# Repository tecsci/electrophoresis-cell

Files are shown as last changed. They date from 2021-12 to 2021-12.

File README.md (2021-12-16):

# Cuba de electroforesis de IORODEO

Links:

* Instructables versión mini: https://www.instructables.com/Gel-electrophoresis-system-mini/
* Sitio oficial documentacion: https://iorodeo.com/pages/documentation

## Fuente

Ver: https://github.com/tecsci/electrophoresis-power-supply

## Otros diseños

Parametric Gel Electrophoresis System: http://www.docubricks.com/viewer.jsp?id=3540694571097352192

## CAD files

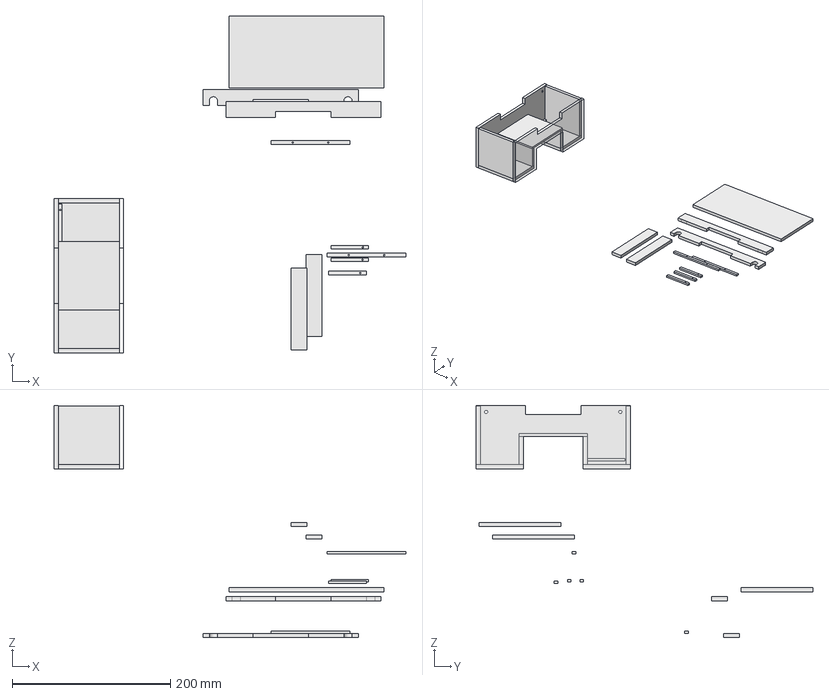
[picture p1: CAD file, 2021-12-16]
modelos/assembly.FCStd
444.4 x 425.5 x 293.3 mm
modelos_parametricos_0.125inch_clear_acrylic001_001
modelos_parametricos_0.125inch_clear_acrylic002_001
modelos_parametricos_0.125inch_clear_acrylic003_001
modelos_parametricos_0.125inch_clear_acrylic004_001
modelos_parametricos_0.125inch_clear_acrylic005_001
modelos_parametricos_0.125inch_clear_acrylic006_001
modelos_parametricos_0.25_inch_blue001_001
modelos_parametricos_0.25_inch_blue002_001
modelos_parametricos_0.25_inch_blue003_001
modelos_parametricos_0.25_inch_blue004_001
modelos_parametricos_0.25_inch_blue005_001
modelos_parametricos_0.25_inch_blue006_001
modelos_parametricos_0.25inch_clear_acrylic001_001
modelos_parametricos_0.25inch_clear_acrylic002_001
modelos_parametricos_0.25inch_clear_acrylic003_001
modelos_parametricos_0.25inch_clear_acrylic004_001
modelos_parametricos_0.25inch_clear_acrylic005_001
modelos_parametricos_0.25inch_clear_acrylic006_001
modelos_parametricos_0.25inch_clear_acrylic007_001
modelos_parametricos_0.125inch_solacryl_001

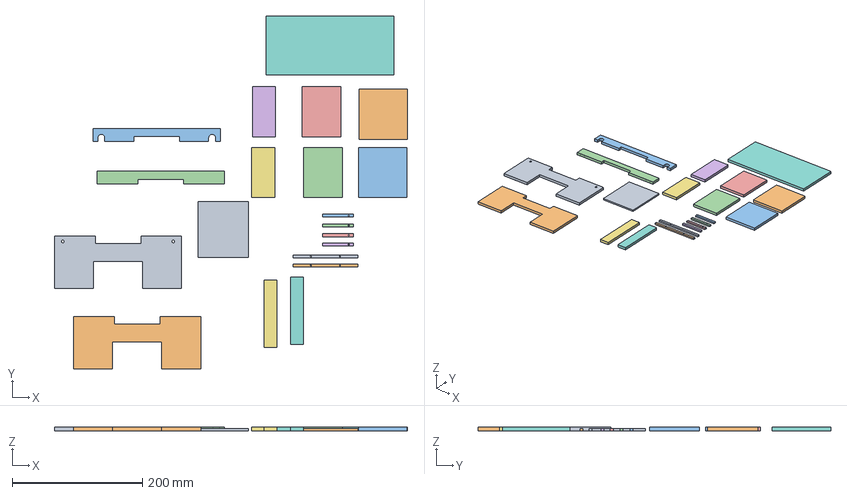
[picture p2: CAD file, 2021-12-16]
modelos/modelos_parametricos.FCStd
541.1 x 541.1 x 5.50 mm
0.125inch_solacryl
0.25inch_clear_acrylic002
0.25inch_clear_acrylic003
0.25inch_clear_acrylic004
0.25inch_clear_acrylic005
0.25inch_clear_acrylic006
0.25inch_clear_acrylic007
0.25inch_clear_acrylic001
0.125inch_clear_acrylic001
0.125inch_clear_acrylic002
0.125inch_clear_acrylic003
0.125inch_clear_acrylic004
0.125inch_clear_acrylic005
0.125inch_clear_acrylic006
0.25_inch_blue001
0.25_inch_blue002
0.25_inch_blue003
0.25_inch_blue004
0.25_inch_blue005
0.25_inch_blue006

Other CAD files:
modelos/modelos_parametricos_lasercut.FCStd
modelos/assembly.stl

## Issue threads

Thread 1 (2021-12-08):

Conseguir alambre de platino

naikymen, 2021-12-08:
Preguntar a Oscar en el IIB si sigue teniendo.

naikymen, 2021-12-20:
# Alternativas al platino

Discusion: https://groups.google.com/g/diybio/c/GWTrmC6vMfc/m/ZTUCxS4BCAAJ

Ideas:

* Uno de platino y otro de NiCr.
* grafito de lapices o de "brushes" de motores eléctricos.
* Los de cobre recubierto en oro no parecen durar, quizas buscar cobre recubierto en platino.
* Consultar con alguien que haya estudiado química (?) @gcorthey

Papers:

* https://iubmb.onlinelibrary.wiley.com/doi/full/10.1002/bmb.20596
* https://www.bio-rad.com/webroot/web/pdf/lse/literature/M1665086EDU.pdf
* Falopa: https://www.ncbi.nlm.nih.gov/pmc/articles/PMC3929695/
* Development of Cost Optimized Horizontal Gel Electrophoresis Running Unit for Developing Countries
* Semi-Automatic Lab-on-PCB System for Agarose Gel Preparation and Electrophoresis for Biomedical Applications

naikymen, 2022-06-06:
Según Pipette Jocket, usar Platino-Iridio 95%-5% es mejor porque resiste la corrosión pero menos frágil mecánicamente.

Y es lo que se vende como "replacement wire".

> Best thing to use is platinum wire that's alloyed with iridium, I think its 95% platinum 5% iridium, or some other precious metal. As corrosion resistant as pure platinum but less brittle, it's sold as replacement wire by Sigma https://www.sigmaaldrich.com/catalog/product/sigma/ep1330?lang=en&region=CA

https://www.youtube.com/watch?v=rbhHr4-dZNE

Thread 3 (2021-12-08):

Agregar modelos de corte al repo

naikymen, 2021-12-08:

naikymen, 2021-12-08:
## [Aca](https://www.instructables.com/Gel-electrophoresis-system-mini/) se dice:

Acrylic materials and design files

From any supplier of acrylic materials (McMaster-Carr, US Plastics etc):

12” x 12” x 1/4" clear acrylic
12" x 12" x 1/4" blue acrylic (or preferred color)
5" x 5" x 1/8" clear acrylic

From McMaster-Carr:

6" x 6" x 1/16" teflon sheet , Cat # 8545K13

From Loop Acrylics:

1/8" solacryl (UV transmissive) - Optional : If you do not need a UV-transmissive gel tray then simply make these parts from regular clear acrylic.

Using the design files attached below, cut the parts from your material - the type of material to use is given in the title of the file. If you do not have access to a laser cutter, you can send the files to any laser cutting service (we use Pololu). These services will also carry most of the material you need with the exception of solacryl.You can also purchase a kit from our online store (IO Rodeo , Cat #IMG-01) for $93. The kit contains all of the laser cut parts and hardware, platinum wire (instead of stainless steel wire) and pre-assembled combs. You will still need to buy the Weld-On.

naikymen, 2021-12-08:
Subí los modelos acá: https://github.com/tecsci/electrophoresis-cell/tree/main/modelos

Son PDFs para cortar.

naikymen, 2021-12-09:
Hoy empecé a armar la cuba con Pepe, y nos falta una parte que sería el cuadrado donde se apoya la cama (flecha negra).

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

También creo que faltan unas piecitas donde se ponen los electrodos (flecha negra con "?").

Creo que es el que está a la derecha en [este](https://github.com/tecsci/electrophoresis-cell/blob/main/modelos/0.125inch_solacryl.pdf) archivo, que no cortamos porque era de otro espesor. Pero no estoy seguro.

Ideas?

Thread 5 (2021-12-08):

Unir las piezas de acrílico

naikymen, 2021-12-08:
- [ ] Completar #2
- [ ] Aprender a pegar las cosas

naikymen, 2021-12-17:
Seria bueno conseguir una escuadra, algun bodoque de madera o metal cúbico por ejemplo.

También ayudaría tener mini sargentos o prensas.

La jerninga con aguja se bancó el cloroformo, pero hubiera sido mejor usar una micropipeta p200. Enchastramos las piezas y la mesa con cloroforomo usando la jeringa.

1. Planear el orden en el que ir pegando las piezas.
2. Usando pedacitos de cinta, alienar y unir las piezas sobre la mesada. Tienen que unirse de forma que los bordes a pegar se toquen al "plegar" una pieza sobre otra.
3. Agregar cloroformo a la cara de cada pieza, y juntarlas. Quizas esperar un poquito a que actúe el cloroformo ayude.
4. Alinearlas bien, usando algo recto (otra pieza, un cubo, escuadra, etc.).
5. Agregar cloroformo a las juntas. Acá observamos que se metía en la junta, llenando algunos espacios que tenían aire.
6. Dejar las piezas secar.

naikymen, 2021-12-17:
La semana que viene practico con Pepe en el IFIBYNE.

naikymen, 2021-12-20:
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

Le puse agua y no pierde :)

Habria que probar darle un poco contra algo para ver si se banca un poco de maltrato.

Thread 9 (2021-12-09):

Adaptar modelos al espesor de acrílico que tenemos.

naikymen, 2021-12-09:

gcorthey, 2021-12-09:
Tenemos 2, 3, 3.2, 5 y 10 mm de espesor de acrílico cristal

naikymen, 2021-12-16:
Hecho: https://github.com/tecsci/electrophoresis-cell/commit/8ea5d3373e02b2473b39efc62527635d13385df9

Modelados en FreeCAD y exportados en SVG:

* https://github.com/tecsci/electrophoresis-cell/blob/main/modelos/partes_0.125.svg
* https://github.com/tecsci/electrophoresis-cell/blob/main/modelos/partes_0.25.svg

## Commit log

2021-12-16 empezar a pasar modelos a freecad
    [modelos_parametricos.FCStd]
2021-12-16 modelos porteados a sketches excepto los de la camita
    [modelos_parametricos.FCStd]
2021-12-16 modelos separados en bodies
    [modelos_parametricos.FCStd, modelos_parametricos_split.FCStd]
2021-12-16 start assembly
    [assembly.FCStd, modelos_parametricos_split.FCStd]
2021-12-16 imported models to assembly
    [assembly.FCStd, modelos_parametricos.FCStd]
2021-12-16 assembly complete
    [assembly.FCStd, modelos_parametricos.FCStd]
2021-12-16 assembly complete (creemos)
    [assembly.FCStd, modelos_parametricos.FCStd]
2021-12-16 assembly complete (creemos que si)
    [assembly.FCStd]
2021-12-16 assembly complete (creemos que sii)
    [assembly.FCStd]
2021-12-16 preparar para lasercut
    [assembly.stl, modelos_parametricos_lasercut.FCStd]
2021-12-16 lasercut prepared
    [modelos_parametricos_lasercut.FCStd]
2021-12-16 lasercut parts SVG export
2021-12-16 lasercut parts SVG export for 5.5mm larger plastic
    [assembly.FCStd, modelos_parametricos.FCStd, modelos_parametricos_lasercut.FCStd]
